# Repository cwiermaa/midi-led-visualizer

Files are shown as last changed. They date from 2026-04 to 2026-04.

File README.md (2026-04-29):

# MIDI LED Visualizer

A MIDI-driven LED strip visualizer for piano input, using Python and Arduino to map real-time note events to configurable color patterns.

---

## Parts List

* WS2812 (NeoPixel) LED strip
* Arduino (tested with Arduino Uno; similar models should also work)
* MIDI keyboard / digital piano
* Desktop machine running Python
* Power supply capable of driving the LED strip

### Power Requirements

For a full 88-key setup:

* WS2812 LEDs can draw up to **~60mA per LED at full brightness (white)**
* For 88 LEDs, plan for **~5A at 5V** as a safe upper bound

In practice, typical usage (colored output, not full white) will draw significantly less, but your power supply should be sized conservatively.

---

## Overview

This project listens to MIDI input and maps active notes to LED colors in real time.

* Notes played on the keyboard light up corresponding LEDs
* Color mappings are configurable
* The **sostenuto pedal** can be used to cycle between different color modes

The system is designed to be simple, responsive, and easy to extend.

---

## Demo (Click to Play)

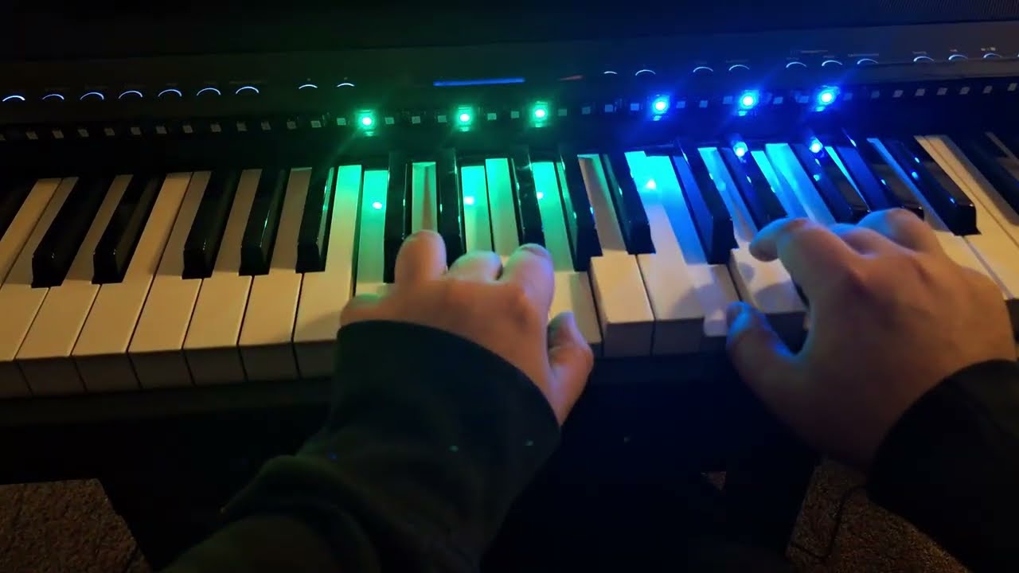
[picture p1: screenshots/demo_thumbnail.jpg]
MIDI LED Visualizer Demo (https://www.youtube.com/watch?v=XFutyCQXSFY)


---

## Repository Structure

```text id="3m5u4w"
3d_printing/
  screenshots/      Example assembly steps
  stl/              Printable components

arduino/
  midi_led_receiver/
    midi_led_receiver.ino

python/
  midi_led_visualizer.py
  config.example.json
  requirements.txt
```

---

## Setup

### 1. Install Python dependencies

```bash id="0c2fye"
pip install -r python/requirements.txt
```

---

### 2. Configure the application

Copy the example config:

```bash id="k0r6wp"
cp python/config.example.json python/config.json
```

Then edit `config.json` to match your setup:

* MIDI input device name
* Serial port (e.g. `COM4`)
* Optional MIDI forwarding

---

### 3. Upload Arduino code

Open:

```text id="txr0zw"
arduino/midi_led_receiver/midi_led_receiver.ino
```

Upload it to your Arduino.

---

### 4. Run the visualizer

```bash id="3k1j4g"
python python/midi_led_visualizer.py --config python/config.json
```

---

## Wiring

### LED Strip → Arduino

* **Data line** → Arduino **Pin 6**
* **5V** → External power supply (recommended for larger strips)
* **GND** → Shared between:

  * Arduino
  * LED strip
  * power supply

⚠️ Important:

* Always ensure **common ground** between all components
* Do not power large LED strips directly from the Arduino

---

## Physical Layout

* The LED strip is oriented so that **lower LED indices correspond to keys on the left side of the keyboard**
* For this reason, it is recommended to position the **Arduino on the left side** of the keyboard

This keeps wiring simple and avoids reversing LED indexing in software.

---

## 3D Printed Mount System

The `3d_printing/` directory contains a modular system for mounting LEDs:

* **Base rails** – main structure with mounting track
* **Bridge rails** – connect segments in a staggered pattern
* **LED holders** – position individual LEDs
* **LED retainers** – secure LEDs in place

See `3d_printing/README.md` for full assembly instructions.

---

## Notes

* This project focuses on **real-time MIDI → LED mapping**, not expressive rendering or advanced visual effects
* Designed to be simple, modular, and easy to modify
* Compatible with most MIDI keyboards and WS2812-style LED strips

---

## Summary

This project demonstrates:

* Real-time MIDI processing in Python
* Serial communication with embedded hardware
* LED control using WS2812 strips
* A modular physical mounting system

---

## Closing

Have fun building!

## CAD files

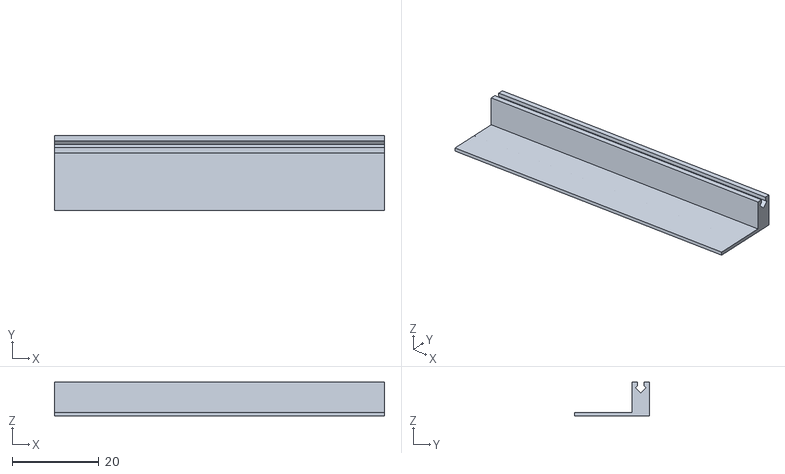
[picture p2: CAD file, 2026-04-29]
3d_printing/stl/bridge_rail.stl
76.2 x 17.3 x 7.79

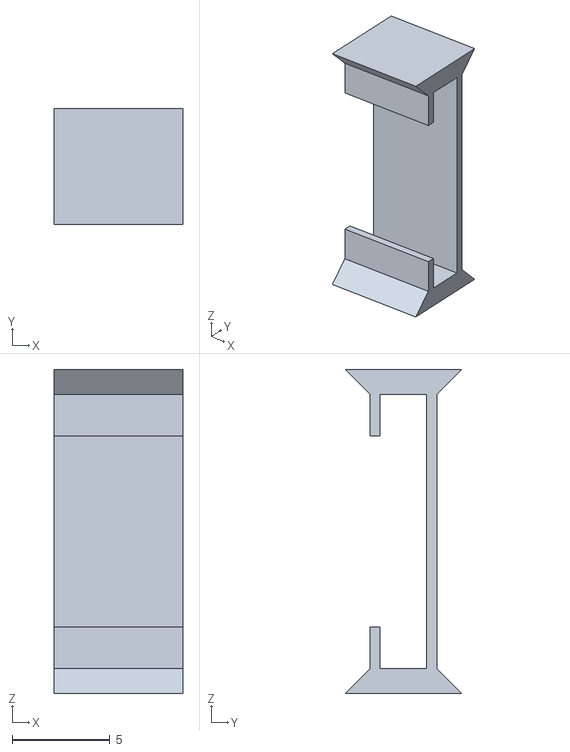
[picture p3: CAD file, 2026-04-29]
3d_printing/stl/led_holder.stl
6.60 x 5.97 x 16.6

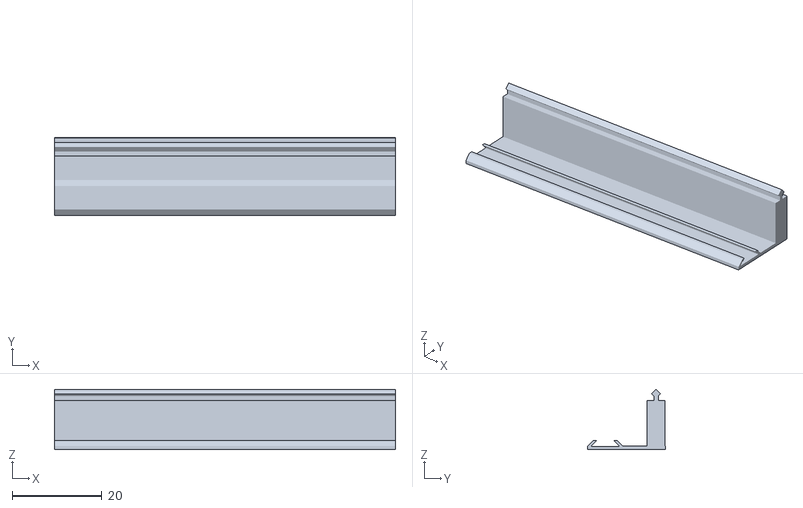
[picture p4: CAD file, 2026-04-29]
3d_printing/stl/base_rail.stl
76.2 x 17.3 x 13.5

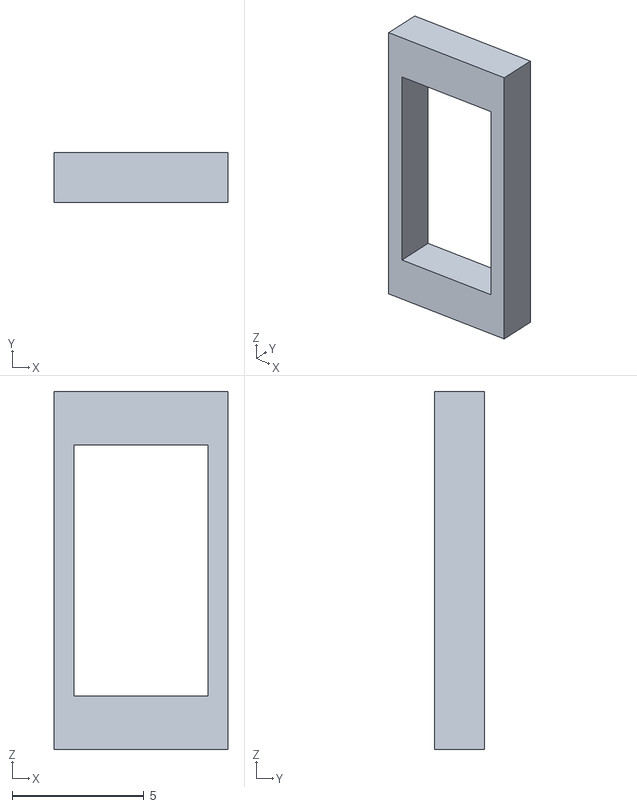
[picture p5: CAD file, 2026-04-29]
3d_printing/stl/led_retainer.stl
6.60 x 1.90 x 13.6

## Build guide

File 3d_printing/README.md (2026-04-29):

# 3D Printing – LED Mount System

This directory contains the printable components used to construct a **modular LED mounting system** for aligning an LED strip with piano keys.

The system allows individual LEDs to be positioned more precisely than their fixed spacing on the strip, while maintaining a clean and stable physical structure.

---

## Components

The system is composed of four parts:

* **Base Rail**
  The primary structural piece. Contains a track for mounting LED holders.

* **Bridge Rail**
  Connects adjacent base rails using a staggered (brick-like) pattern for improved rigidity.

* **LED Holder**
  Slides into the base rail and positions a single LED.

* **LED Retainer**
  A small press-fit piece used to secure the LED strip within the holder.

---

## Assembly Overview

The following steps demonstrate how the system is assembled. These examples are shown independently of a full keyboard setup, but reflect the intended workflow.

---

### 1. Attach Retainer to LED

Snap a **retainer** onto the front of an LED on the strip.

This piece ensures the LED will sit snugly inside the holder.

*(image here)*

---

### 2. Adjust LED Spacing

Introduce a small **kink** in the LED strip between adjacent LEDs.

This allows LEDs to be positioned closer together than their fixed spacing on the strip.

*(image here)*

---

### 3. Insert LED Holder

Slide an **LED holder** into the track on the base rail.

Position it approximately where the LED should align (e.g., corresponding to a key).

*(image here)*

---

### 4. Mount LED into Holder

Insert the LED (with retainer attached) into the holder.

The retainer should hold the LED securely in place.

*(image here)*

---

### 5. Repeat and Extend

Repeat steps 1–4 for each LED.

As you fill a base rail:

* Add additional base rails as needed
* Connect them using **bridge rails**

⚠️ Note:

* Avoid adding bridge rails too early, as they can obstruct access while placing LEDs
* Attach bridges only after the section is mostly complete

---

## Rail Layout

Rails are designed to be assembled in a staggered pattern:

```text
----|----|----|   (Bridge Rail)
--|----|----|--   (Base Rail)
```

This improves structural stability while allowing flexible length construction.

---

## Notes

* This system is intended as a **modular mounting approach**, not a fixed one-size solution
* Exact positioning may vary depending on keyboard geometry and LED strip type
* Demonstration images show isolated assembly steps rather than a full installation

---

## Files

```text
stl/
  base_rail.stl
  bridge_rail.stl
  led_holder.stl
  led_retainer.stl
```

---

## Summary

This mounting system provides:

* Adjustable LED positioning
* Modular, extendable structure
* Secure retention of LED strip segments

It is designed to work alongside the MIDI-driven LED visualizer system in this repository.

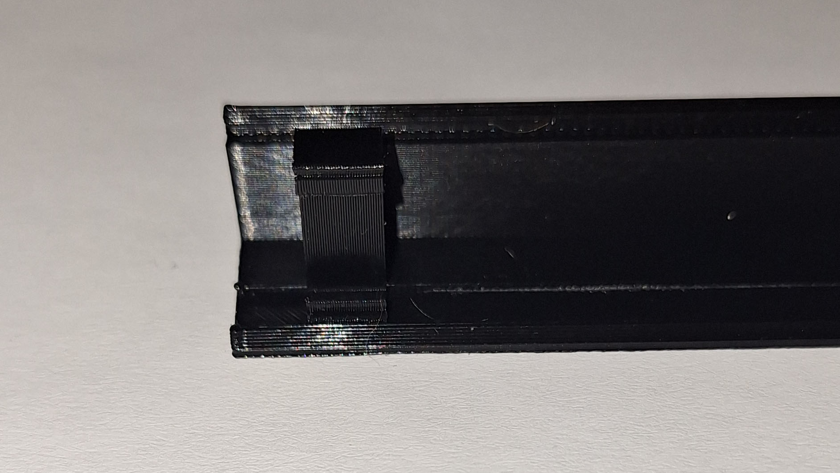
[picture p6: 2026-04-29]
3d_printing/screenshots/3.jpg

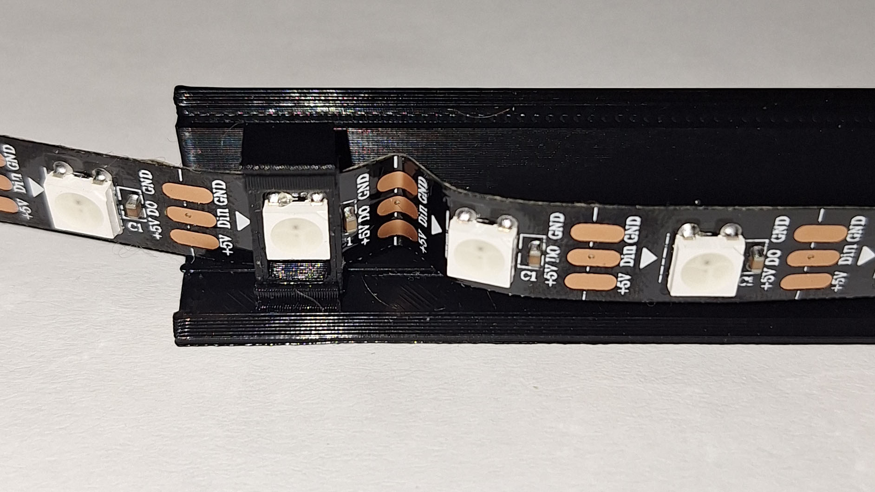
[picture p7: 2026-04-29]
3d_printing/screenshots/4.jpg

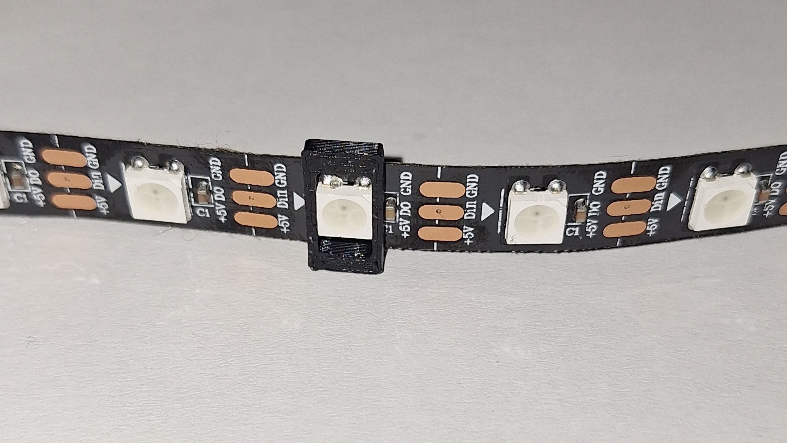
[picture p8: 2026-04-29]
3d_printing/screenshots/1.jpg

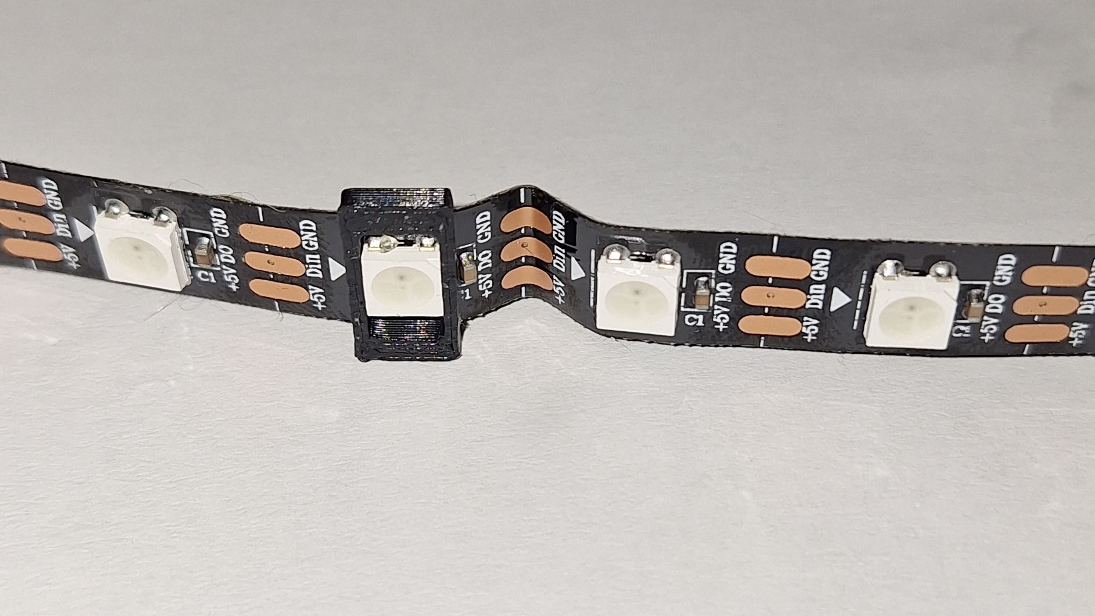
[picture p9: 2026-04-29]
3d_printing/screenshots/2.jpg

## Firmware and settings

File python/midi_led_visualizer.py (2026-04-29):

import argparse
import json
import math
import queue
import threading
import time
from dataclasses import dataclass
from pathlib import Path
from typing import Optional

import mido
import serial


@dataclass
class KeyState:
    key_index: int
    midi_note: int
    is_down: bool = False
    color: tuple[int, int, int] = (0, 0, 0)


class MidiLedVisualizer:
    def __init__(self, config: dict):
        self.config = config

        self.midi_queue: queue.Queue[mido.Message] = queue.Queue()

        self.lowest_midi_note: int = config.get("lowest_midi_note", 21)
        self.num_keys: int = config.get("num_keys", 88)
        self.led_offset: int = config.get("led_offset", 0)

        self.sustain_cc: int = config.get("sustain_cc", 64)
        self.sostenuto_cc: int = config.get("sostenuto_cc", 66)

        self.frame_rate: int = config.get("frame_rate", 60)
        self.period: float = 1.0 / self.frame_rate

        self.sustain_on: bool = False
        self.sostenuto_was_down: bool = False

        self.color_maps: list[dict] = config.get("color_maps", [])
        if not self.color_maps:
            raise ValueError("config must contain at least one color map")

        self.color_map_index: int = 0

        self.key_states = [
            KeyState(
                key_index=i,
                midi_note=self.lowest_midi_note + i,
            )
            for i in range(self.num_keys)
        ]

        self.serial_connection: Optional[serial.Serial] = None

    # ---------- Device listing ----------

    @staticmethod
    def list_midi_devices() -> None:
        print("MIDI input devices:")
        for name in mido.get_input_names():
            print(f"  IN : {name}")

        print("\nMIDI output devices:")
        for name in mido.get_output_names():
            print(f"  OUT: {name}")

    # ---------- MIDI ----------

    def start_midi_thread(self) -> None:
        input_name = self.config.get("midi_input_name")
        output_name = self.config.get("midi_output_name")
        forwarding_enabled = self.config.get("enable_midi_forwarding", False)

        if not input_name:
            raise ValueError("config must define midi_input_name")

        thread = threading.Thread(
            target=self._midi_listener,
            args=(input_name, output_name, forwarding_enabled),
            daemon=True,
        )
        thread.start()

    def _midi_listener(
        self,
        input_name: str,
        output_name: Optional[str],
        forwarding_enabled: bool,
    ) -> None:
        print(f"Opening MIDI input: {input_name}")

        if forwarding_enabled:
            if not output_name:
                raise ValueError(
                    "enable_midi_forwarding is true, but midi_output_name is not set"
                )

            print(f"Forwarding MIDI to: {output_name}")

            with mido.open_input(input_name) as inport, mido.open_output(output_name) as outport:
                for msg in inport:
                    self.midi_queue.put(msg)
                    outport.send(msg)
        else:
            with mido.open_input(input_name) as inport:
                for msg in inport:
                    self.midi_queue.put(msg)

    # ---------- Serial / Arduino ----------

    def connect_serial(self) -> None:
        port = self.config.get("serial_port")
        baud_rate = self.config.get("baud_rate", 115200)

        if not port:
            raise ValueError("config must define serial_port")

        print(f"Opening serial port: {port} @ {baud_rate}")
        self.serial_connection = serial.Serial(port, baud_rate, timeout=1)

        # Give Arduino time to reset after serial connection opens.
        time.sleep(2)

        print("Waiting for Arduino READY...")
        while True:
            line = self.serial_connection.readline().decode(errors="ignore").strip()
            if line == "READY":
                print("Arduino ready.")
                return

    def send_led_frame(self) -> None:
        if self.serial_connection is None:
            raise RuntimeError("Serial connection is not open")

        active_states = [
            state
            for state in self.key_states
            if state.color != (0, 0, 0)
        ]

        if active_states:
            payload = b"".join(
                bytes(
                    [
                        self._clamp_byte(state.key_index + self.led_offset),
                        self._clamp_byte(state.color[0]),
                        self._clamp_byte(state.color[1]),
                        self._clamp_byte(state.color[2]),
                    ]
                )
                for state in active_states
            )
        else:
            # Send a harmless out-of-range LED index to indicate "no active LEDs".
            # The Arduino clears the strip every frame before applying chunks.
            payload = bytes([255, 0, 0, 0])

        self.serial_connection.reset_input_buffer()
        self.serial_connection.write(payload)

        while True:
            response = self.serial_connection.readline().decode(errors="ignore").strip()
            if response == "DONE":
                break

    # ---------- Color maps ----------

    def current_color_map(self) -> dict:
        return self.color_maps[self.color_map_index]

    def cycle_color_map(self) -> None:
        self.color_map_index = (self.color_map_index + 1) % len(self.color_maps)
        color_map = self.current_color_map()
        print(f"Color map: {color_map.get('name', self.color_map_index)}")

        # Optional behavior: clear currently held colors when switching modes.
        # Comment this out if you want currently-held notes to keep old colors.
        for state in self.key_states:
            if state.is_down:
                state.color = self.color_for_key(state.key_index)

    def color_for_key(self, key_index: int) -> tuple[int, int, int]:
        color_map = self.current_color_map()
        default = tuple(color_map.get("default", [0, 0, 0]))

        for rule in color_map.get("ranges", []):
            if rule["from"] <= key_index <= rule["to"]:
                return tuple(rule["color"])

        return default

    # ---------- Main state updates ----------

    def process_midi_messages(self) -> None:
        while not self.midi_queue.empty():
            msg = self.midi_queue.get()

            if msg.type == "note_on":
                # MIDI convention: note_on velocity 0 is equivalent to note_off.
                if getattr(msg, "velocity", 0) == 0:
                    self.handle_note_off(msg.note)
                else:
                    self.handle_note_on(msg.note)

            elif msg.type == "note_off":
                self.handle_note_off(msg.note)

            elif msg.type == "control_change":
                self.handle_control_change(msg.control, msg.value)

    def handle_note_on(self, midi_note: int) -> None:
        key_index = midi_note - self.lowest_midi_note

        if not 0 <= key_index < self.num_keys:
            return

        state = self.key_states[key_index]
        state.is_down = True
        state.color = self.color_for_key(key_index)

    def handle_note_off(self, midi_note: int) -> None:
        key_index = midi_note - self.lowest_midi_note

        if not 0 <= key_index < self.num_keys:
            return

        state = self.key_states[key_index]
        state.is_down = False

        if not self.sustain_on:
            state.color = (0, 0, 0)

    def handle_control_change(self, control: int, value: int) -> None:
        is_down = value > 0

        if control == self.sustain_cc:
            self.sustain_on = is_down

            if not self.sustain_on:
                self.clear_released_keys()

        elif control == self.sostenuto_cc:
            # Cycle once on pedal-down, not repeatedly while held.
            if is_down and not self.sostenuto_was_down:
                self.cycle_color_map()

            self.sostenuto_was_down = is_down

    def clear_released_keys(self) -> None:
        for state in self.key_states:
            if not state.is_down:
                state.color = (0, 0, 0)

    # ---------- Run loop ----------

    def run(self) -> None:
        self.start_midi_thread()
        self.connect_serial()

        print(f"Starting loop at {self.frame_rate} FPS")
        print(f"Color map: {self.current_color_map().get('name', self.color_map_index)}")

        try:
            while True:
                start = time.time()

                self.process_midi_messages()
                self.send_led_frame()

                elapsed = time.time() - start
                time.sleep(max(0, self.period - elapsed))

        except KeyboardInterrupt:
            print("\nExiting on Ctrl+C.")

        finally:
            if self.serial_connection is not None:
                self.serial_connection.close()
                print("Serial connection closed.")

    @staticmethod
    def _clamp_byte(value: int) -> int:
        return max(0, min(255, int(math.floor(value))))


def load_config(path: Path) -> dict:
    if not path.exists():
        raise FileNotFoundError(f"Config file not found: {path}")

    with path.open("r", encoding="utf-8") as f:
        return json.load(f)


def main() -> None:
    parser = argparse.ArgumentParser(
        description="MIDI-driven LED visualizer for piano/keyboard input."
    )

    parser.add_argument(
        "--config",
        default="config.json",
        help="Path to config JSON file. Default: config.json",
    )

    parser.add_argument(
        "--list-midi",
        action="store_true",
        help="List available MIDI input/output devices and exit.",
    )

    args = parser.parse_args()

    if args.list_midi:
        MidiLedVisualizer.list_midi_devices()
        return

    config = load_config(Path(args.config))
    app = MidiLedVisualizer(config)
    app.run()


if __name__ == "__main__":
    main()

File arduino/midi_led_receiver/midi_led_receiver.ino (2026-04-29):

#include <Adafruit_NeoPixel.h>

#define PIN 6         // Pin connected to the data line of the WS2812 LED strip
#define NUM_LEDS 100

const int CHUNK_SIZE = 4;
const int MAX_CHUNKS = 88; // Adjust as needed
const int TOTAL_BYTES = CHUNK_SIZE * MAX_CHUNKS;
const int UNUSED_LED_OFFSET = 0; //Adjust as needed

byte buffer[TOTAL_BYTES];
int bytesRead = 0;
bool readyToProcess = false;

Adafruit_NeoPixel strip(NUM_LEDS, PIN, NEO_GRB + NEO_KHZ800);

void setup() {
  strip.begin();
  strip.show(); // Initialize all pixels to 'off'
  Serial.begin(115200);
  Serial.setTimeout(1000 / 60);
  while (!Serial); // Wait for Serial to connect (if needed)
  Serial.println("READY");  // Signal to Python to start

  pinMode(3, OUTPUT);
  pinMode(4, OUTPUT);
  pinMode(5, OUTPUT);
  pinMode(7, OUTPUT);
  digitalWrite(3, HIGH);
  digitalWrite(4, HIGH);
  digitalWrite(5, HIGH);
  digitalWrite(7, HIGH);
}

void loop() {
  if (Serial.available() && !readyToProcess) {
    bytesRead = Serial.readBytes(buffer, TOTAL_BYTES);
    if (bytesRead % CHUNK_SIZE == 0) {
      readyToProcess = true;
    }
  }

  if (readyToProcess) {
    for (int i = 0; i < NUM_LEDS; i++) {
        strip.setPixelColor(i, strip.Color(0, 0, 0));
    }
    // Process all received 4-byte chunks
    for (int i = 0; i < bytesRead; i += CHUNK_SIZE) {
        int ledNum = buffer[i + 0];
        int red = buffer[i + 1];
        int green = buffer[i + 2];
        int blue = buffer[i + 3];
        if (ledNum < NUM_LEDS) {
          strip.setPixelColor(ledNum + UNUSED_LED_OFFSET, strip.Color(red, green, blue));
        }
    }
    strip.show();

    // Reset state
    readyToProcess = false;
    bytesRead = 0;

    // Signal Python we're done
    Serial.println("DONE");
  }
}
